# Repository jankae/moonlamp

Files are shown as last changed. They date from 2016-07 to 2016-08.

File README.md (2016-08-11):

# moonlamp
An AVR based moonlamp which always lights up just as the real moon.

<p align="left">
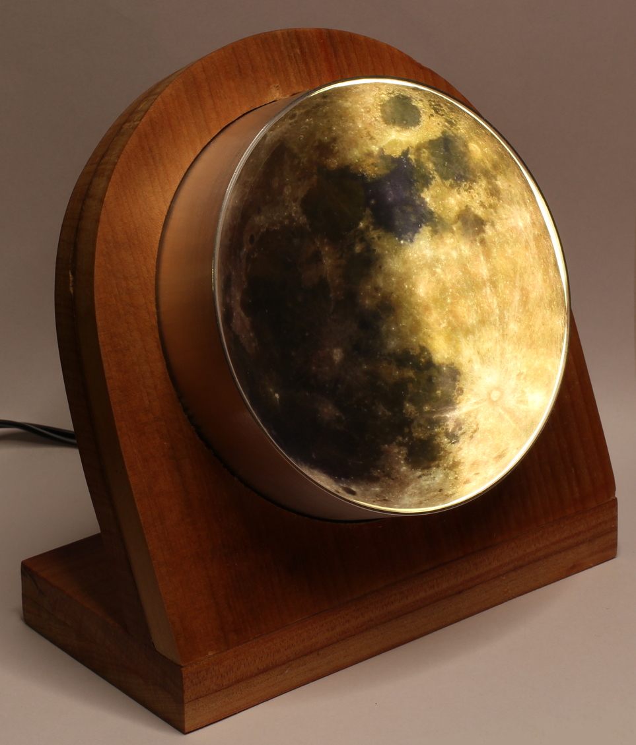
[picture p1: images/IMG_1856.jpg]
  
</p>

Using a RTC and pre-programmed full-moon dates this lamp shows the moon in its current phase. Which also means you can't turn it on at all on a new moon ;)

## Operation
Touch the metal part to turn it on and off. The brightness can be conrolled by touching it for a longer time.

## Compiling & Flashing
The makefile is set up in such a way that the program is always (re-)compiled before flashing it. During this compiler-run, date and time will be hard-coded in the programm and written to the RTC at first startup. Thus, it is not necessary to set the RTC manually.

1. Adjust the makefile to your programmer
2. Setting fuses:

  ```
  cd software/moonlamp
  make fuses
  ```
3. Flash the program:

  ```
  make flash
  ```

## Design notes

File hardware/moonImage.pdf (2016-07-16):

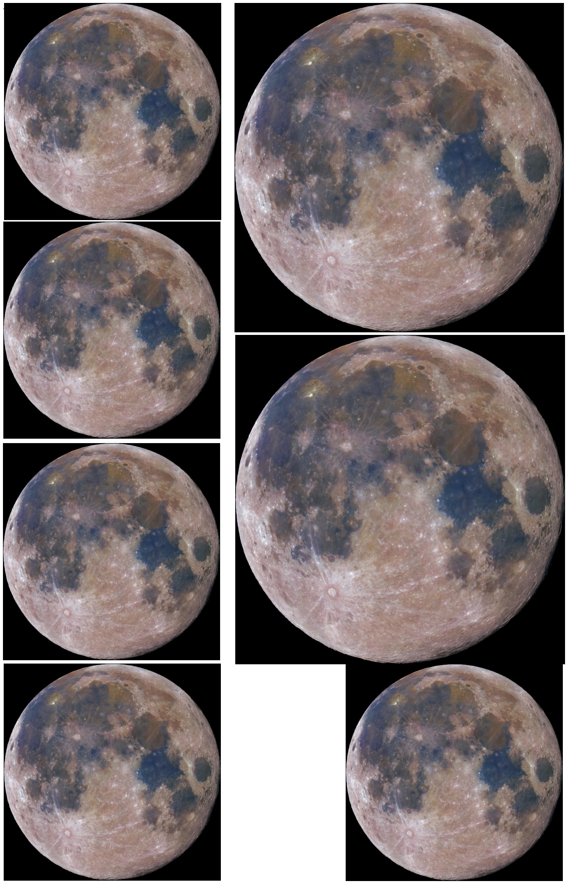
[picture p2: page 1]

+++

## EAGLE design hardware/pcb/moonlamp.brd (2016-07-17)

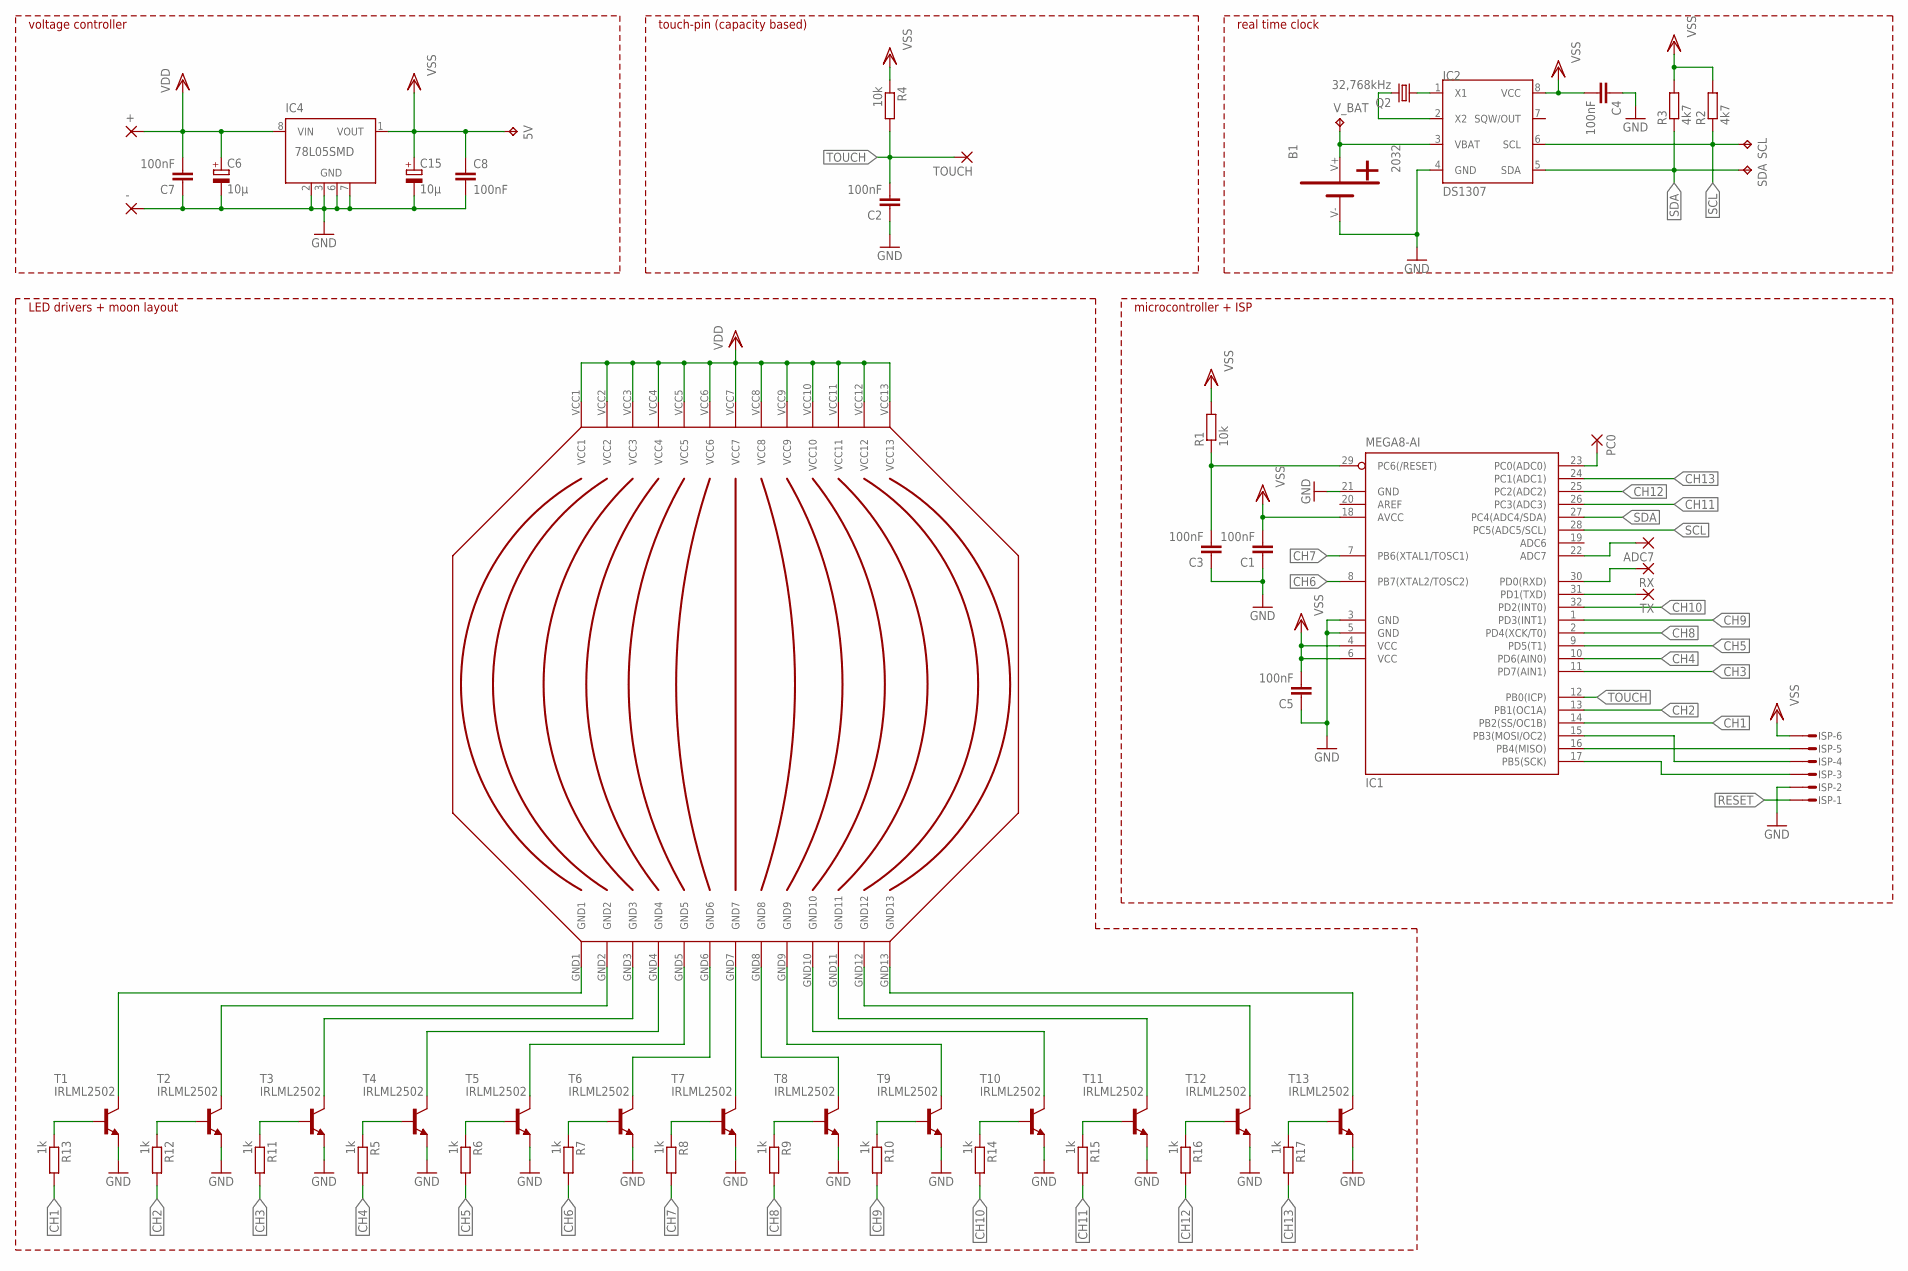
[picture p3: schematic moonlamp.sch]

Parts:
5V: TPB1,27; B1,27
+: SMD5; SMD2,54-5,08
-: SMD5; SMD2,54-5,08
ADC7: SMD2; SMD1,27-2,54
B1: 2032
C1, C2, C4, C5: 100nF; C0603
C3, C7, C8: 100nF; C0603K
C6, C15: 10µ; SMC_A
IC1: MEGA8-AI; TQFP32-08
IC2: DS1307; SOIC-8
IC4: 78L05SMD; SO08
ISP: MICROMATCH-6SMF; MMT-F-SMD-6
PC0: SMD2; SMD1,27-2,54
Q2: 32,768kHz; MM20SS
R1, R4: 10k; R0603
R2, R3: 4k7; R0603
R5, R6, R7, R8, R9, R10, R11, R12, R13, R14, R15, R16, R17: 1k; R1206
RX: SMD2; SMD1,27-2,54
SCL: TPB1,27; B1,27
SDA: TPB1,27; B1,27
T1, T2, T3, T4, T5, T6, T7, T8, T9, T10, T11, T12, T13: IRLML2502; SOT23
TOUCH: SMD2; SMD1,27-2,54
TX: SMD2; SMD1,27-2,54
U$1: MOON
V_BAT: TPB1,27; B1,27

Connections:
CH1: IC1.14 (PB2(SS/OC1B)), R13.2
CH2: IC1.13 (PB1(OC1A)), R12.2
CH3: IC1.11 (PD7(AIN1)), R11.2
CH4: IC1.10 (PD6(AIN0)), R5.2
CH5: IC1.9 (PD5(T1)), R6.2
CH6: IC1.8 (PB7(XTAL2/TOSC2)), R7.2
CH7: IC1.7 (PB6(XTAL1/TOSC1)), R8.2
CH8: IC1.2 (PD4(XCK/T0)), R9.2
CH9: IC1.1 (PD3(INT1)), R10.2
CH10: IC1.32 (PD2(INT0)), R14.2
CH11: IC1.26 (PC3(ADC3)), R15.2
CH12: IC1.25 (PC2(ADC2)), R16.2
CH13: IC1.24 (PC1(ADC1)), R17.2
GND: -.1, B1.V-, C1.1, C2.1, C3.1, C4.1, C5.1, C6.-, C7.1, C8.2, C15.-, IC1.3 (GND), IC1.5 (GND), IC1.21 (GND), IC2.4 (GND), IC4.2 (GND), IC4.3 (GND), IC4.6 (GND), IC4.7 (GND), ISP.2, T1.2 (E), T2.2 (E), T3.2 (E), T4.2 (E), T5.2 (E), T6.2 (E), T7.2 (E), T8.2 (E), T9.2 (E), T10.2 (E), T11.2 (E), T12.2 (E), T13.2 (E)
unnamed: ADC7.1, IC1.22 (ADC7)
unnamed: R5.1, T4.1 (B)
unnamed: IC1.31 (PD1(TXD)), TX.1
unnamed: R6.1, T5.1 (B)
unnamed: R7.1, T6.1 (B)
unnamed: R8.1, T7.1 (B)
unnamed: R9.1, T8.1 (B)
unnamed: R10.1, T9.1 (B)
unnamed: B1.V+, IC2.3 (VBAT), V_BAT.TP
unnamed: R11.1, T3.1 (B)
unnamed: R12.1, T2.1 (B)
unnamed: IC2.1 (X1), Q2.1
unnamed: IC2.2 (X2), Q2.4 (2)
unnamed: R13.1, T1.1 (B)
unnamed: R14.1, T10.1 (B)
unnamed: R15.1, T11.1 (B)
unnamed: R16.1, T12.1 (B)
unnamed: R17.1, T13.1 (B)
unnamed: T7.3 (C), U$1.GND7
unnamed: IC1.30 (PD0(RXD)), RX.1
unnamed: IC1.17 (PB5(SCK)), ISP.3
unnamed: IC1.16 (PB4(MISO)), ISP.5
unnamed: T1.3 (C), U$1.GND1
unnamed: T2.3 (C), U$1.GND2
unnamed: T3.3 (C), U$1.GND3
unnamed: T4.3 (C), U$1.GND4
unnamed: T5.3 (C), U$1.GND5
unnamed: T6.3 (C), U$1.GND6
unnamed: T8.3 (C), U$1.GND8
unnamed: T9.3 (C), U$1.GND9
unnamed: T10.3 (C), U$1.GND10
unnamed: T11.3 (C), U$1.GND11
unnamed: T12.3 (C), U$1.GND12
unnamed: T13.3 (C), U$1.GND13
unnamed: IC1.23 (PC0(ADC0)), PC0.1
unnamed: IC1.15 (PB3(MOSI/OC2)), ISP.4
RESET: C3.2, IC1.29 (PC6(/RESET)), ISP.1, R1.1
SCL: IC1.28 (PC5(ADC5/SCL)), IC2.6 (SCL), R2.1, SCL.TP
SDA: IC1.27 (PC4(ADC4/SDA)), IC2.5 (SDA), R3.1, SDA.TP
TOUCH: C2.2, IC1.12 (PB0(ICP)), R4.2, TOUCH.1
VDD: +.1, C6.+, C7.2, IC4.8 (VIN), U$1.VCC1, U$1.VCC2, U$1.VCC3, U$1.VCC4, U$1.VCC5, U$1.VCC6, U$1.VCC7, U$1.VCC8, U$1.VCC9, U$1.VCC10, U$1.VCC11, U$1.VCC12, U$1.VCC13
VSS: 5V.TP, C1.2, C4.2, C5.2, C8.1, C15.+, IC1.4 (VCC), IC1.6 (VCC), IC1.18 (AVCC), IC2.8 (VCC), IC4.1 (VOUT), ISP.6, R1.2, R2.2, R3.2, R4.1

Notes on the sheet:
voltage controller
touch-pin (capacity based)
real time clock
microcontroller + ISP
LED drivers + moon layout

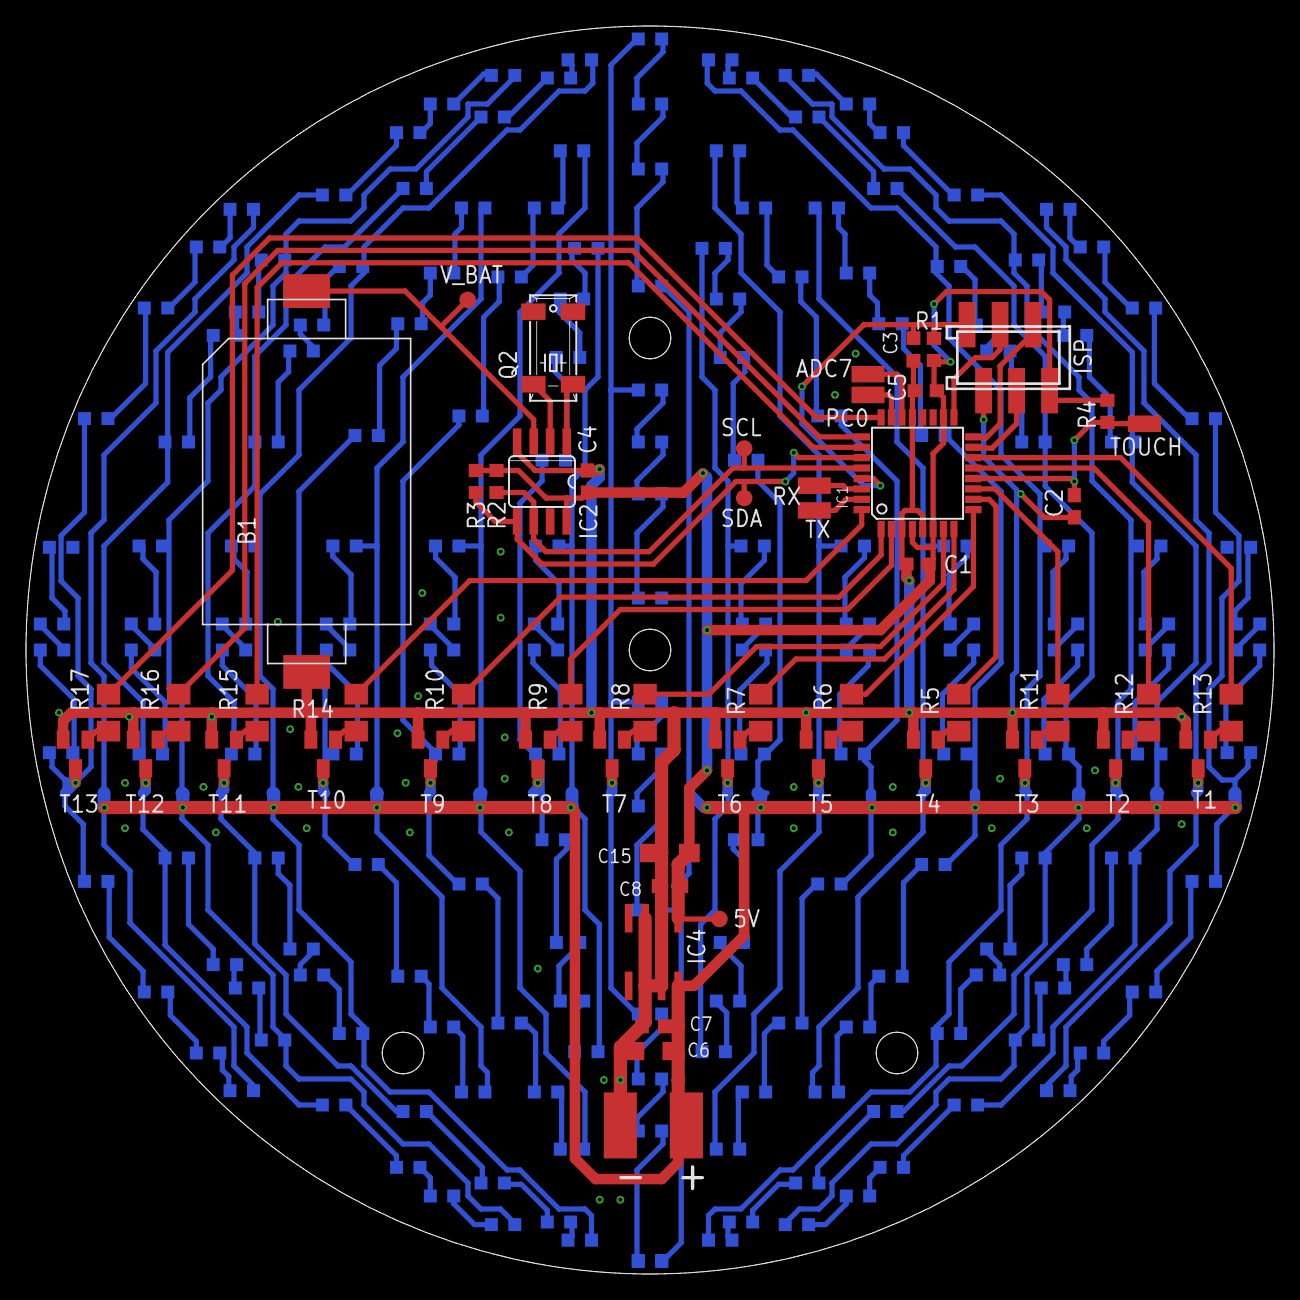
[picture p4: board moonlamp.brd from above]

Board: 2 copper layers, 96.0 x 96.0 mm, 57 parts (1 on the bottom side), 56 nets.

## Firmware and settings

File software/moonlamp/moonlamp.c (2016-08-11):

#include <avr/io.h>

#include "moon.h"
#include "eeprom.h"
#include "ds1307.h"
#include "systime.h"
#include "touch.h"

int main(void) {
	time_Init();
	uart_init();
	i2c_init();
	touch_Init();
	sei();

	DS1307_Init();

	uart_puts("moonlamp V0.9 start\n");
	struct date date;
	struct time time;
	eeprom_Read(&date, &time);

	uart_puts("EEPROM date/time: ");
	uart_putDate(date);
	uart_putc('/');
	uart_putTime(time);
	// compare EEPROM time with compile time
	if ((date.day != COMPILE_DAY) || (date.month != COMPILE_MONTH)
			|| (date.year != (COMPILE_YEAR - 2000))
			|| (time.second != COMPILE_SECOND)
			|| (time.minute != COMPILE_MINUTE) || (time.hour != COMPILE_HOUR)) {
		// EEPROM date/time doesn't match compile date/time
		// -> device has just been flashed, write compile date/time to RTC
		date.day = COMPILE_DAY;
		date.month = COMPILE_MONTH;
		date.year = (COMPILE_YEAR - 2000);
		time.second = COMPILE_SECOND;
		time.minute = COMPILE_MINUTE;
		time.hour = COMPILE_HOUR;
		uart_puts("\nEEPROM doesn't match compile time:\n");
		uart_puts("Compile date/time: ");
		uart_putDate(date);
		uart_putc('/');
		uart_putTime(time);
		// set RTC
		uart_puts("\nSetting RTC...\n");
		DS1307_setTime(time);
		DS1307_setDate(date);
		// save in EEPROM
		uart_puts("Updating EEPROM...\n");
		eeprom_Write(date, time);
	} else {
		uart_puts("\nEEPROM matches compile time\n");
	}
	// at this point the RTC has either just been set or still contains a valid
	// time and date (device hasn't been flashed before current start-up)
	DS1307_getDate(&date);
	DS1307_getTime(&time);
	uart_puts("RTC date/time: ");
	uart_putDate(date);
	uart_putc('/');
	uart_putTime(time);
	uart_putc('\n');

	moon_init();

	// light up moon once to show device is working (it might be new moon)
	// activate all elements
	moon_SetElementsLeft(13);
	uint8_t i;
	for (i = 0; i < 10; i++) {
		moon_SetPWM(i * i);
		time_WaitMs(50);
	}
	moon_SetPWM(255);
	time_WaitMs(50);
	for (i = 9; i > 0; i--) {
		moon_SetPWM(i * i);
		time_WaitMs(50);
	}
	moon_SetPWM(0);

	// sanity check for RTC
	if (date.year < 16) {
		// can't be right, year must be at least 2016
		uart_puts("ERROR: RTC invalid\n");
		moon_Error(2);
	}

	moon_Update(date);

	uint8_t brightness = 5;
	uint8_t oldDay;
	uint8_t on = 1;
	uint8_t increasingBrightness = 1;
	uint8_t holding = 0;
	uint16_t changeTimeout;
	uint16_t timeUpdateTimeout = time_SetTimeout(10000);
	while (1) {
		time_WaitMs(5);
		touch_Update();
		/*********************************
		 * Step 1: Evaluate touch control
		 ********************************/
		if (touch_Tapped()) {
			on = !on;
			if (on) {
				uart_puts("Moonlamp on\n");
			} else {
				uart_puts("Moonlamp off\n");
			}
		} else if (touch_Holding()) {
			if (!on) {
				uart_puts("Moonlamp on\n");
				on = 1;
			}
			if (!holding || time_TimeoutElapsed(changeTimeout)) {
				// only change brightness every 200ms
				changeTimeout = time_SetTimeout(200);
				// sweep brightness
				if (increasingBrightness) {
					if (brightness < 10) {
						brightness++;
					} else {
						increasingBrightness = 0;
					}
				} else {
					if (brightness > 1) {
						brightness--;
					} else {
						increasingBrightness = 1;
					}
				}
				holding = 1;
				uart_puts("New brightness: ");
				uart_putInteger(brightness);
				uart_putc('\n');
			}
		} else {
			holding = 0;
		}
		/*********************************
		 * Step 2: get current date
		 ********************************/
		if (time_TimeoutElapsed(timeUpdateTimeout)) {
			oldDay = date.day;
			DS1307_getDate(&date);
			struct date date2;
			DS1307_getDate(&date2);
			if (date.day == date2.day && date.month == date2.month
					&& date.year == date2.year) {
				// both dates are the same
				// -> probably no I2C transmission error
				if (date.day >= 1 && date.day <= 31 && date.month >= 1
						&& date.month <= 12 && date.year >= 16
						&& date.year <= 99) {
					// date seems to be valid
					/*********************************
					 * Step 3: Update moon state
					 ********************************/
					if (oldDay != date.day) {
						moon_Update(date);
					}
					timeUpdateTimeout = time_SetTimeout(10000);
				}
			}
		}
		/*********************************
		 * Step 4: Set moon PWM
		 ********************************/
		if (on) {
			uint16_t pwm = brightness * brightness;
			if (pwm > 255)
				pwm = 255;
			moon_SetPWM(pwm);
		} else {
			moon_SetPWM(0);
		}
	}
}

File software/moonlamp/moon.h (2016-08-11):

#ifndef MOON_H_
#define MOON_H_

#include <avr/io.h>
#include <avr/interrupt.h>
#include "uart.h"
#include "dates.h"
#include "systime.h"

/*
 * Bits  7   6   5   4   3   2   1   0
 * PB    6   7   -   -   -   1   2   -
 * PC    -   -   -   -  11  12  13   -
 * PD    3   4   5   8   9  10   -   -
 */
#define MOON_NUM_ELEMENTS		13

#define MOON_ELEMENT1_DDR		DDRB
#define MOON_ELEMENT1_PORT		MaskPORTB
#define MOON_ELEMENT1_PIN		(2)

#define MOON_ELEMENT2_DDR		DDRB
#define MOON_ELEMENT2_PORT		MaskPORTB
#define MOON_ELEMENT2_PIN		(1)

#define MOON_ELEMENT3_DDR		DDRD
#define MOON_ELEMENT3_PORT		MaskPORTD
#define MOON_ELEMENT3_PIN		(7)

#define MOON_ELEMENT4_DDR		DDRD
#define MOON_ELEMENT4_PORT		MaskPORTD
#define MOON_ELEMENT4_PIN		(6)

#define MOON_ELEMENT5_DDR		DDRD
#define MOON_ELEMENT5_PORT		MaskPORTD
#define MOON_ELEMENT5_PIN		(5)

#define MOON_ELEMENT6_DDR		DDRB
#define MOON_ELEMENT6_PORT		MaskPORTB
#define MOON_ELEMENT6_PIN		(7)

#define MOON_ELEMENT7_DDR		DDRB
#define MOON_ELEMENT7_PORT		MaskPORTB
#define MOON_ELEMENT7_PIN		(6)

#define MOON_ELEMENT8_DDR		DDRD
#define MOON_ELEMENT8_PORT		MaskPORTD
#define MOON_ELEMENT8_PIN		(4)

#define MOON_ELEMENT9_DDR		DDRD
#define MOON_ELEMENT9_PORT		MaskPORTD
#define MOON_ELEMENT9_PIN		(3)

#define MOON_ELEMENT10_DDR		DDRD
#define MOON_ELEMENT10_PORT		MaskPORTD
#define MOON_ELEMENT10_PIN		(2)

#define MOON_ELEMENT11_DDR		DDRC
#define MOON_ELEMENT11_PORT		MaskPORTC
#define MOON_ELEMENT11_PIN		(3)

#define MOON_ELEMENT12_DDR		DDRC
#define MOON_ELEMENT12_PORT		MaskPORTC
#define MOON_ELEMENT12_PIN		(2)

#define MOON_ELEMENT13_DDR		DDRC
#define MOON_ELEMENT13_PORT		MaskPORTC
#define MOON_ELEMENT13_PIN		(1)

struct {
	uint8_t MaskPORTB;
	uint8_t MaskPORTC;
	uint8_t MaskPORTD;
	uint8_t OffPORTB;
	uint8_t OffPORTC;
	uint8_t OffPORTD;
	uint8_t brightness;
	uint8_t pwmCycle;
} moon;

/**
 * \brief Initializes ports and variables, sets brightness to zero
 */
void moon_init(void);

/**
 * \brief Calculates the number of days between two given dates
 *
 * \param date1 First date
 * \param date2 Second date
 * \return Number of days between date1 and date2
 */
uint8_t moon_DaysBetweenDates(struct date date1, struct date date2);

/**
 * \brief Calculates the moon state to a given date
 *
 * \param date The date at which the moon state should be calculated
 * \return Moonstate:
 * 			128: full moon
 * 			1 to 127: waxing moon
 * 			0: new moon
 * 			-1 to -128: waning moon
 */
int8_t moon_calculateState(struct date date);

/**
 * \brief Lights up a number of elements, starting from the left side (waning moon)
 *
 * \param elements Number of elements to light up (0-13)
 */
void moon_SetElementsLeft(uint8_t elements);

/**
 * \brief Lights up a number of elements, starting from the right side (waxing moon)
 *
 * \param elements Number of elements to light up (0-13)
 */
void moon_SetElementsRight(uint8_t elements);

/**
 * \brief Updates the moon state with a given date
 *
 * \param date The current date
 */
void moon_Update(struct date date);

/**
 * \brief Sets the intensity of the moon LEDs
 *
 * \param pwm 8-bit PWM (0-255)
 */
void moon_SetPWM(uint8_t pwm);

void moon_Error(uint8_t blink);

#endif

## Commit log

2016-07-16 Hardware: new eagle layout + gerber. Software: Old code + a few modifications
    [moonlamp.brd, moonlamp.sch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]
2016-07-17 replace parameters with date/time structs
    [ds1307.c]
2016-07-17 added touch pin evaluation
2016-07-17 move pcb files in dedicated folder
    [moonlamp.brd, moonlamp.sch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]
2016-07-17 deleted renamed files
    [moonlamp.brd, moonlamp.sch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]
2016-07-17 initial CAD drawing
2016-07-17 cleaned up schematic
    [moonlamp.brd, moonlamp.sch]
2016-07-19 bugfix: wrong GPIO used
    [touch.c]
2016-07-19 more uart put functions
2016-07-19 Touch measurement completely changed
    - using ADC instead of normal pin (touch must be connected to PC0
    now)
2016-07-19 Various bugfixes and improvements. Seems to be running now
    [moon.h, moonlamp.c]
2016-07-19 various improvements
    - ds1307: initialization of DS1307 (turns off square wave output,
    reduces current consumption from backup-battery)
    - i2c_master: timeouts in i2c operations
    - systime: global ms-timer. Individual timeouts must be saved locally
    - moon: PWM tricks. Got rid of flickering lights at low/high PWM values
2016-07-19 tracking of touch.threshold -> dynamically adjust to surrounding capacity
2016-07-19 touch evaluation changed (works for now, might not work in metal case)
    [touch.c]
2016-08-11 some changes regarding interrupts and timing
    - increased F_CPU from 1MHz to 8MHz
    - changed soft PWM code, now easier to understand
    - moved touch evaluation out of interrupt (produced jitter on soft PWM)
    [moon.h, moonlamp.c, touch.c]
